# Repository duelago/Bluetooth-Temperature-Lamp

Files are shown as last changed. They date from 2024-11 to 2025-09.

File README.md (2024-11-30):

# <h1>Blåtandstermometerlampan</h1>

En bordslampa som byter färg beroende på yttertemperaturen och som även visar tempen på en liten OLED-skärm.
Lampan kommunicerar med en billig blåtandstermometer som vi installerar alternativ firmware på och placerar utomhus (i närheten).
Kodat i Arduino IDE. Termometern vi ansluter till måste flashas en gång med hjälp av ett pythonscript och lödkolven måste fram. 

Jag printar lådan och locket i PLA med 0.6 nozzle på min Prusa.<br>
Själva toppen av lampan till höger i bild är printad med 0.4 nozzle. Två perimetrar, ingen infill i själva lampan men fästet längst ner har infill. (Prusa slicer har stöd för olika infill på olika lager) Pinnen är ett metallsugrör från ICA

Screenshot 2024-11-10 at 17 25 36 copy

bluetoothesp32

<h2>Själva hjärnan i operationen är en ESP32</h2>

Detta behövs:<br>
ESP32 38 pin- Testad med denna modellen från AliExpress (Jag kör med micro usb-anslutning eftersom jag har ett rejält lager med sådana kablar) https://www.aliexpress.com/item/1005006900641832.html 
Blåtandstermometer - https://www.aliexpress.com/item/1005006458594110.html
LED  - https://www.aliexpress.com/item/1005004950092116.html
OLED-skärm https://www.aliexpress.com/item/32804426981.html
USB-to-TTL adapter (Vet inte vilken som är bra, men typ denna) https://www.aliexpress.com/item/1005004742270942.html
Metallsugrör från ICA eller Amazon https://t.ly/_2JY1
1 st motstånd 100 Ohm
2 skruvar M2.5 
1 micro usb-kabel
Krympslang till LEDen https://www.aliexpress.com/item/1005006991396293.html 
Dupontkablar (female-female) 3st 30cm  och ett gäng 10cm https://www.aliexpress.com/item/1005005501503609.html

3D-printade detaljer i PLA











<h2>Steg ett är att flasha firmware på vår termometer</h2>
Plocka isär den och löd fast kablar enligt denna bild. Dessa ska du sedan koppla till din USB-to-TTL adapter
<b>rx-tx<br>
tx-rx<br>
vbat+- 3.3v<br>
vbat- - ground<br>
rest - reset</b>

bth01

Följ instruktionerna här för hur du flashar din BTH01  https://github.com/pvvx/THB2 <br> (Denna modellen har jag, men det finns varianter https://pvvx.github.io/BTH01/ )<br>

Först måste du flasha .hex filen via terminalen med hjälp av python scriptet. (Finns även bland mina filer) <br>
Typ så här görs det på min mac:<p>


Din COM-port heter något annat. Den får du luska reda på.
<h2>Web-interfacet där du uppdaterar din firmware i fortsättningen ser ut så här</h2>



När du flashat klart, klickar du på  READ under config-taben och ta reda på termometerns MAC-adress. Denna adress klistrar du in i .ino filen före du kompilerar lampans firmware

Sen är det bara att kompilera [.ino](https://github.com/duelago/bluetoothlamp/blob/main/bluetooth-esp32.ino) filen i Arduino IDE. Se till att korrekt esp32 är vald som board och att alla bibliotek är installerade.



<h2>nRF Connect</h2>

Tips. Denna appen är utmärkt för att se mer info om din blåtandstermometer samt för felsökning. Klarar av att decoda temperaturen även när vi kör custom firmware
Screenshot_2024-11-11-08-14-45-61_b5a5c5cb02ca09c784c5d88160e2ec24

<h1>Snöflingelampan</h1>

Denna lampa är en vidareutveckling av blåtandslampan. Utöver temperatur har jag placerat en co2-sensor i lådan, samt kör med sex LEDs istället för endast en. Resultatet är att vi kan presentera mer information genom att varje LED teoretiskt går att styra individuellt. I denna versionen har jag delat upp LEDsen tre och tre där ena sidan visar temp och den andra koldioxidhalten i rummet. Flasha snowflake.ino och studera kopplingsschemat nedan. Själva blåtandsdelen är identisk.

Jag har även gjort en lampa med extra allt. Snowflake Web, snowflake-web.ino. Denna är uppkopplad på wifi och har förutom temp och c02, stöd för en extern väderstation från Holfuy, samt upplyser om när en viss låt spelas på Mix Megapol. Kolla min Whamageddonlampa för mer info. I denna lampa har vi ett webinterface och kan även göra firmwareuppdateringar via websidan (OTA).

https://www.youtube.com/watch?v=6aXL863onwM


bluetooth

Denna co2-sensorn, Scd40 använder jag i snöflingan. Dyr men bra.
https://www.aliexpress.com/item/1005006275318058.html
I övrigt är det bara att följa instruktionerna för blåtandslampan. Skillnaden är att vi måste seriekoppla 6 leds. Hur det görs ser du på skissen. Data in till data ut. Co2-sensorn kan köras på både 3.3V och 5V, men 5 volt rekommenderas.



<h3>Snowflake Web</h3>
Jag kunde inte låta bli så i denna versionen kan du varna för Last Christmas på Megapol, aka Whamageddonlampan, samt se data i en lokal webserver. Denna lampa kräver dock lite installation för att funka och är sämre att ge bort i present, men här har du allt lull-lull. 


<h3>Retroversion med HPDL1414 skärm</h3>

retro

HPDL-1414 finns att köpa här https://www.aliexpress.com/item/32604923707.html

-----
<br>
Mer dokumentation om blåtandsgrunkorna<br> 
https://github.com/pvvx/ATC_MiThermometer#readme

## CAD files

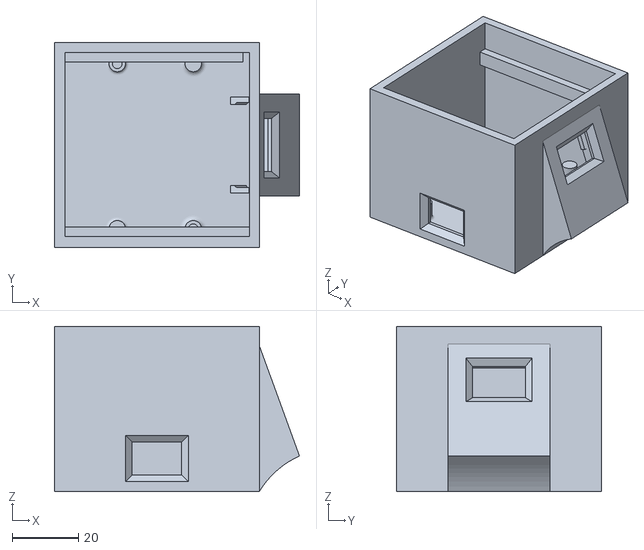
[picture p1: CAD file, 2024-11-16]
bluetooth-lamp-esp32-box.stl
74.1 x 62.0 x 50.0

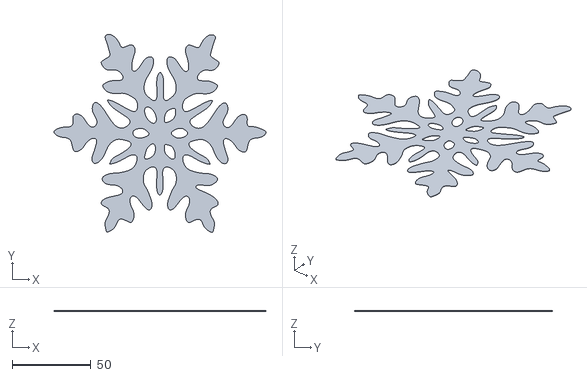
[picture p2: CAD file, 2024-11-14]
snowflake_Part2.stl
135.0 x 126.1 x 0.6

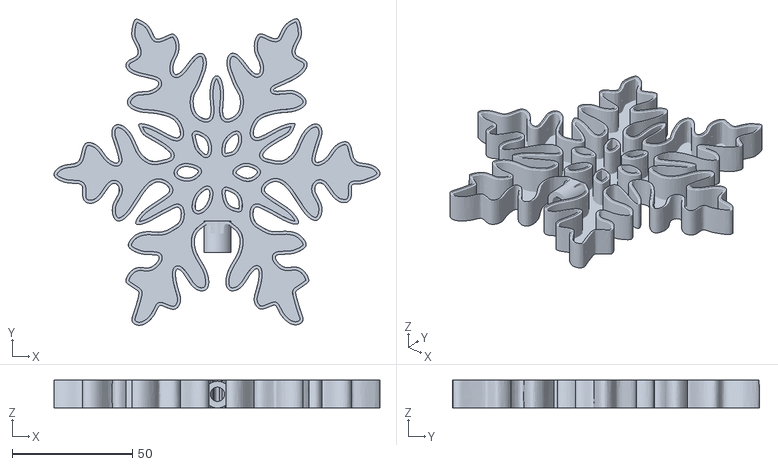
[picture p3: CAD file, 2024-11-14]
snowflake-part1.stl
135.3 x 127.3 x 11.6

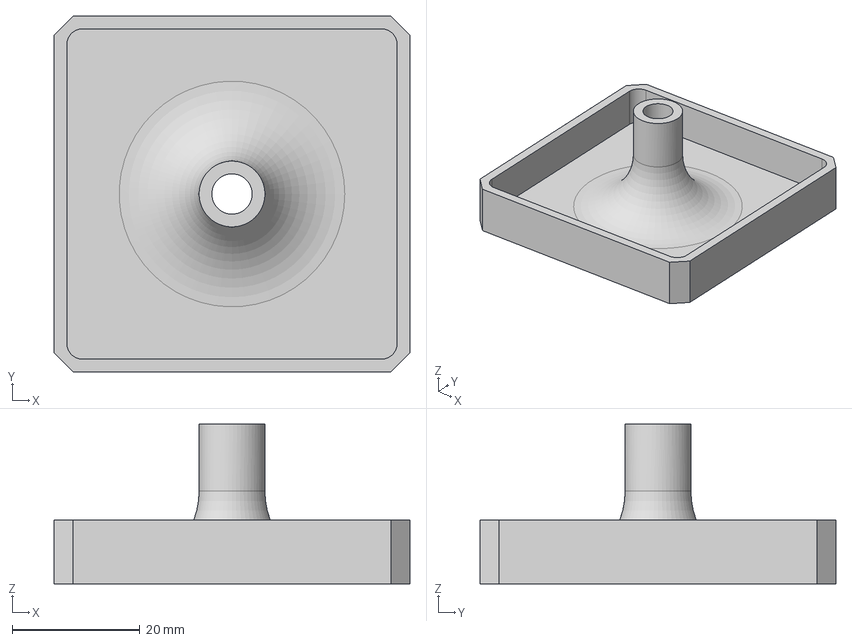
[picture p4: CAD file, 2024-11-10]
bluetooth-box-lid.step
55.7 x 55.7 x 25.0 mm

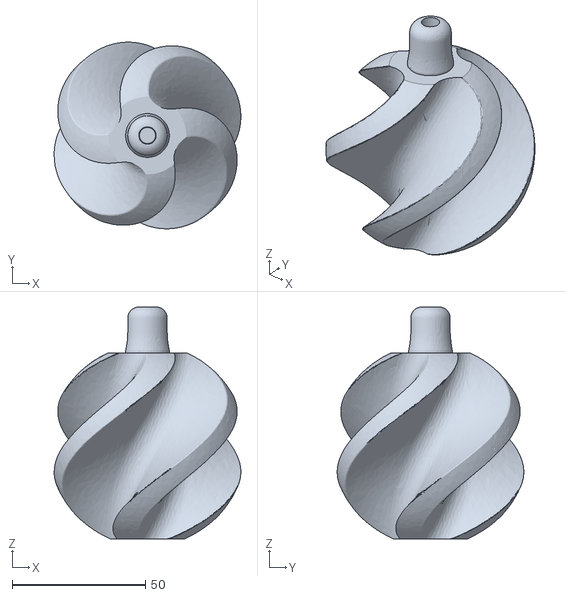
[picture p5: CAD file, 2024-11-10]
bluetooth-lampshade.stl
70.0 x 70.0 x 87.0

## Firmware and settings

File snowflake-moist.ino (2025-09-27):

#include <FastLED.h>
#include <Wire.h>
#include <Adafruit_GFX.h>
#include <Adafruit_SSD1306.h>
#include <NimBLEDevice.h>
#include <WiFiManager.h>
#include <WebServer.h>
#include <ElegantOTA.h>
#include <HTTPClient.h>  
#include <ArduinoJson.h> 
#include <EEPROM.h>  

#define SONG_TITLE_ADDRESS 0
#define DRY_VALUE_ADDRESS 50
#define WET_VALUE_ADDRESS 54

// OLED Display definitions  
#define SCREEN_WIDTH 64
#define SCREEN_HEIGHT 48
#define OLED_RESET -1

#define NUM_LEDS 6
#define DATA_PIN 4

#define OLED_SDA 21
#define OLED_SCL 22

#define MOISTURE_PIN 32

WebServer server(80);

CRGB leds[NUM_LEDS];
// Fixed display declaration for older library
Adafruit_SSD1306 display(OLED_RESET);

// Set the interval for all sensor checks to 45 seconds (45,000 milliseconds)
unsigned long previousMoistureCheckMillis = 0;
unsigned long previousTitleCheckMillis = 0;
unsigned long previousWindUpdateMillis = 0; // Add a variable to track wind update time
const unsigned long sensorCheckInterval = 45000; // 45 seconds (45,000 milliseconds)

const char* apiUrl = "https://listenapi.planetradio.co.uk/api9.2/nowplaying/mme";

unsigned long previousBLEMillis = 0; // Stores the last time BLE scan was triggered
const unsigned long scanInterval = 10000; // Time between BLE scans (e.g., 10 seconds)

const char* apiHost = "api.holfuy.com";

// The updated interval for all checks
const unsigned long updateInterval = 45000;  // 45 seconds in milliseconds

float temperature = 0.0;
float windSpeed = 0.0;
bool hasReceivedReading = false;
const std::string targetMacAddress = "38:1f:8d:97:bd:5d";

//bool blockLEDUpdates = false; // Flag to block other LED updates
// Global flag to control LED behavior
bool isBlinking = false;

// Moisture sensor variables
int moistureValue = 0;
int dryValue = 3000;  // Default dry calibration value
int wetValue = 1000;  // Default wet calibration value

NimBLEScan* pBLEScan;
const int scanTime = 5;

// Function prototypes
void displayCenteredText(String text, int textSize, int yPosition);
void setTemperatureLEDColor(float roundedTemperature);
void setWindSpeedLEDColor(float windSpeed);
void handleMoistureLEDs();
void blinkRedGreen(int duration);
void blinkRedLEDs();
void decodeServiceData(const std::string& payload);
void checkWiFiConnection();
uint16_t decodeLittleEndianU16(uint8_t lowByte, uint8_t highByte);
void testDisplay();
void testLEDs();

// WiFi reconnection function
void checkWiFiConnection() {
    if (WiFi.status() != WL_CONNECTED) {
        Serial.println("WiFi disconnected. Attempting to reconnect...");
        WiFi.disconnect();
        delay(1000);
        
        // Try to reconnect
        WiFi.begin();
        
        int attempts = 0;
        while (WiFi.status() != WL_CONNECTED && attempts < 20) {
            delay(500);
            Serial.print(".");
            attempts++;
        }
        
        if (WiFi.status() == WL_CONNECTED) {
            Serial.println();
            Serial.print("WiFi reconnected! IP: ");
            Serial.println(WiFi.localIP());
            Serial.print("Signal strength (RSSI): ");
            Serial.println(WiFi.RSSI());
        } else {
            Serial.println();
            Serial.println("Failed to reconnect to WiFi");
        }
    }
}

void blinkRedGreen(int duration) {
    unsigned long start = millis();
    unsigned long prevBlinkMillis = 0;
    int interval = 999; // Blink interval in milliseconds
    bool isRedOnLed4 = true; // Start with LED 4 as red

    while (millis() - start < duration) {
        unsigned long currentMillis = millis();

        // Check if it's time to toggle the color
        if (currentMillis - prevBlinkMillis >= interval) {
            prevBlinkMillis = currentMillis; // Save the current time

            if (isRedOnLed4) {
                leds[4] = CRGB::Cyan;   // Set LED at index 4 to red
                leds[5] = CRGB::Magenta; // Set LED at index 5 to green
            } else {
                leds[4] = CRGB::Magenta; // Set LED at index 4 to green
                leds[5] = CRGB::Cyan;   // Set LED at index 5 to red
            }

            FastLED.show();
            isRedOnLed4 = !isRedOnLed4; // Toggle the LED colors
        }

        // Do other non-blocking tasks here if needed
    }
}

// Function to write values to EEPROM
void writeDryValueToEEPROM(int value) {
    EEPROM.writeInt(DRY_VALUE_ADDRESS, value);
    EEPROM.commit();
}

void writeWetValueToEEPROM(int value) {
    EEPROM.writeInt(WET_VALUE_ADDRESS, value);
    EEPROM.commit();
}

// Function to read values from EEPROM
int readDryValueFromEEPROM() {
    int value = EEPROM.readInt(DRY_VALUE_ADDRESS);
    return (value == 0 || value == -1) ? 3000 : value; // Default if not set
}

int readWetValueFromEEPROM() {
    int value = EEPROM.readInt(WET_VALUE_ADDRESS);
    return (value == 0 || value == -1) ? 1000 : value; // Default if not set
}

// Function to write the song title to EEPROM
void writeSongTitleToEEPROM(const String& songTitle) {
    int len = songTitle.length();
    for (int i = 0; i < len; i++) {
        EEPROM.write(SONG_TITLE_ADDRESS + i, songTitle[i]);
    }
    EEPROM.write(SONG_TITLE_ADDRESS + len, '\0');  // Null-terminate the string
    EEPROM.commit();  // Save changes to EEPROM
}

// Function to read the song title from EEPROM
String readSongTitleFromEEPROM() {
    String songTitle = "";
    for (int i = SONG_TITLE_ADDRESS; i < SONG_TITLE_ADDRESS + 32; i++) {
        char c = EEPROM.read(i);
        if (c == '\0') break;
        songTitle += c;
    }
    return songTitle;
}

// Function to handle the form for setting the song title
void handleSetSongTitle() {
    String songTitle = server.arg("songTitle");  // Get the song title from the form
    if (songTitle.length() > 0) {
        writeSongTitleToEEPROM(songTitle);  // Store it in EEPROM
    }
    server.send(200, "text/html", "<html><body><h1>Song Title Saved!</h1><a href='/'>Back</a></body></html>");
}

// Function to handle calibration form
void handleCalibration() {
    String dryVal = server.arg("dryValue");
    String wetVal = server.arg("wetValue");
    
    if (dryVal.length() > 0) {
        dryValue = dryVal.toInt();
        writeDryValueToEEPROM(dryValue);
    }
    
    if (wetVal.length() > 0) {
        wetValue = wetVal.toInt();
        writeWetValueToEEPROM(wetValue);
    }
    
    server.send(200, "text/html", "<html><body><h1>Calibration Values Saved!</h1><a href='/'>Back</a></body></html>");
}

// Function to make an HTTP request and parse JSON with retry and timeout settings
String getSongTitle() {
    // Check and reconnect WiFi if needed
    checkWiFiConnection();
    
    if (WiFi.status() != WL_CONNECTED) {
        Serial.println("WiFi still not connected, cannot fetch song title");
        return "WiFi disconnected";
    }
    
    Serial.println("Attempting to connect to: " + String(apiUrl));
    
    HTTPClient http;
    
    // Configure HTTP client with timeouts
    http.setTimeout(10000); // 10 second timeout
    http.setConnectTimeout(5000); // 5 second connection timeout
    http.setReuse(false); // Don't reuse connections
    
    // Add headers
    http.addHeader("User-Agent", "ESP32-Snowflake/1.0");
    http.addHeader("Accept", "application/json");
    
    if (!http.begin(apiUrl)) {
        Serial.println("HTTP begin failed");
        return "HTTP begin error";
    }
    
    int httpResponseCode = http.GET();
    Serial.print("HTTP Response Code: ");
    Serial.println(httpResponseCode);

    if (httpResponseCode > 0) {
        String payload = http.getString();
        Serial.println("HTTP Response received, length: " + String(payload.length()));
        
        if (payload.length() > 0) {
            Serial.println("HTTP Response: " + payload.substring(0, min(200, (int)payload.length()))); // Show first 200 chars

            // Parse JSON
            StaticJsonDocument<1024> doc;
            DeserializationError error = deserializeJson(doc, payload);

            if (error) {
                Serial.print("JSON Deserialization failed: ");
                Serial.println(error.f_str());
                http.end();
                return "Error parsing JSON";
            }

            // Extract the song title from the JSON response
            const char* songTitle = doc["TrackTitle"];
            http.end();
            return songTitle ? String(songTitle) : "No song data";
        } else {
            Serial.println("Empty response received");
            http.end();
            return "Empty response";
        }
    } else {
        Serial.print("HTTP GET request failed, error: ");
        Serial.println(http.errorToString(httpResponseCode).c_str());
        Serial.print("WiFi status: ");
        Serial.println(WiFi.status());
        http.end();
        return "HTTP error";
    }
}

// Function to compare two strings case-insensitively
bool caseInsensitiveCompare(const char* str1, const char* str2) {
    while (*str1 && *str2) {
        if (tolower(*str1) != tolower(*str2)) {
            return false;
        }
        str1++;
        str2++;
    }
    return *str1 == *str2;
}

// Helper function to decode a little-endian 16-bit unsigned integer
uint16_t decodeLittleEndianU16(uint8_t lowByte, uint8_t highByte) {
    return (uint16_t)((highByte << 8) | lowByte);
}

// Function to decode the raw service data and update the temperature
void decodeServiceData(const std::string& payload) {
    if (payload.length() >= 14 && payload[0] == 0x40) {
        int16_t temp_int = (payload[6] & 0xff) | ((payload[7] & 0xff) << 8);
        temperature = temp_int / 100.0;
        Serial.print("Temperature: ");
        Serial.print(temperature);
        Serial.println(" °C");

        hasReceivedReading = true;  // Set flag to true once we receive a valid reading

        // Update display and LED color
        setTemperatureLEDColor(round(temperature));
        displayCenteredText(String((int)round(temperature)), 2, 32);
    }
}

// Callback class to handle BLE advertisements
class MyAdvertisedDeviceCallbacks : public NimBLEAdvertisedDeviceCallbacks {
    void onResult(NimBLEAdvertisedDevice* advertisedDevice) {
        if (caseInsensitiveCompare(advertisedDevice->getAddress().toString().c_str(), targetMacAddress.c_str())) {
            if (advertisedDevice->haveServiceData()) {
                decodeServiceData(advertisedDevice->getServiceData());
            } else {
                Serial.println("No service data available.");
            }
        }
    }
};

// FIXED: Function to display centered text on the OLED screen
void displayCenteredText(String text, int textSize, int yPosition) {
    display.clearDisplay();
    display.setTextSize(textSize);
    display.setTextColor(WHITE, BLACK);
    display.setTextWrap(false);
    
    // For 64x48 display - much smaller calculations needed
    int charWidth = 6 * textSize;  // Each character width including spacing
    int charHeight = 8 * textSize; // Each character height
    
    int textWidth = text.length() * charWidth;
    
    // Center horizontally on 64-pixel wide screen
    int xPosition = (SCREEN_WIDTH - textWidth) / 2;
    
    // For 48-pixel tall screen, adjust Y positioning
    int finalYPosition = yPosition;
    if (yPosition == -1) {
        // Center vertically
        finalYPosition = (SCREEN_HEIGHT - charHeight) / 2;
    }
    
    // Bounds checking for small screen
    if (xPosition < 0) xPosition = 0;
    if (xPosition + textWidth > SCREEN_WIDTH) xPosition = SCREEN_WIDTH - textWidth;
    if (xPosition < 0) xPosition = 0; // If text is too wide, align left
    
    if (finalYPosition < 0) finalYPosition = 0;
    if (finalYPosition + charHeight > SCREEN_HEIGHT) finalYPosition = SCREEN_HEIGHT - charHeight;
    
    display.setCursor(xPosition, finalYPosition);
    display.print(text);
    display.display();
    
    Serial.print("64x48 Display - Text: '");
    Serial.print(text);
    Serial.print("' Size: ");
    Serial.print(textSize);
    Serial.print(" Pos: (");
    Serial.print(xPosition);
    Serial.print(",");
    Serial.print(finalYPosition);
    Serial.print(") TextWidth: ");
    Serial.print(textWidth);
    Serial.print(" Screen: ");
    Serial.print(SCREEN_WIDTH);
    Serial.print("x");
    Serial.println(SCREEN_HEIGHT);
}

void updateWindSpeed() {
    // Check and reconnect WiFi if needed
    checkWiFiConnection();
    
    if (WiFi.status() != WL_CONNECTED) {
        Serial.println("WiFi still not connected, cannot fetch wind speed");
        return;
    }
    
    HTTPClient client;
    String url = "https://api.holfuy.com/live/?s=214&pw=correcthorsebatterystaple&m=JSON&tu=C&su=m/s";
    
    Serial.println("Attempting to connect to Holfuy API for wind data: " + url);
    
    // Configure HTTP client with timeouts
    client.setTimeout(10000); // 10 second timeout
    client.setConnectTimeout(5000); // 5 second connection timeout
    client.setReuse(false); // Don't reuse connections
    
    // Add headers
    client.addHeader("User-Agent", "ESP32-Snowflake/1.0");
    client.addHeader("Accept", "application/json");

    // Begin the HTTP request to the API
    if (!client.begin(url)) {
        Serial.println(F("Holfuy API connection failed"));
        return;
    }

    // Send the HTTP GET request
    int httpCode = client.GET();
    Serial.print("Holfuy HTTP Response Code: ");
    Serial.println(httpCode);

    // Check if the GET request was successful
    if (httpCode > 0) {
        String payload = client.getString();  // Get the response payload
        
        // Print the response to the Serial monitor
        Serial.println("Holfuy Response length: " + String(payload.length()));
        if (payload.length() > 0) {
            Serial.println("Holfuy Response: " + payload.substring(0, min(200, (int)payload.length())));

            // Parse the JSON response
            StaticJsonDocument<512> doc;
            DeserializationError error = deserializeJson(doc, payload);

            if (!error) {
                // Successfully parsed the JSON, get the wind speed
                float speed = doc["wind"]["speed"];
                Serial.print("Wind Speed Holfuy: ");
                Serial.print(speed);
                Serial.println(" m/s");

                // Set the LED color based on the wind speed
                setWindSpeedLEDColor(speed);
                windSpeed = speed;  // Store the wind speed
            } else {
                // Handle JSON parsing error
                Serial.print(F("JSON deserialization failed: "));
                Serial.println(error.f_str());
            }
        } else {
            Serial.println("Empty response from Holfuy API");
        }
    } else {
        // If the GET request failed
        Serial.println("Holfuy HTTP request failed, error code: " + String(httpCode));
        Serial.print("WiFi status: ");
        Serial.println(WiFi.status());
    }

    // Close the connection
    client.end();
}

void setWindSpeedLEDColor(float windSpeed) {
    // LEDs at index 2 and 3 for wind speed (0-25+ m/s scale)
    if (windSpeed >= 0 && windSpeed < 3) {
        fill_solid(leds + 2, 2, 0xFF44DD);  // Pink (0-3 m/s)
    } else if (windSpeed >= 3 && windSpeed < 6) {
        fill_solid(leds + 2, 2, 0x0006FF);  // Blue (3-6 m/s)
    } else if (windSpeed >= 6 && windSpeed <= 9) {
        fill_solid(leds + 2, 2, 0x00FF06);  // Green (6-9 m/s)
    } else if (windSpeed > 9 && windSpeed <= 12) {
        fill_solid(leds + 2, 2, 0xFFF600);  // Yellow (9-12 m/s)
    } else if (windSpeed > 12 && windSpeed <= 18) {
        fill_solid(leds + 2, 2, 0xFFA500);  // Orange (12-18 m/s)
    } else if (windSpeed > 18 && windSpeed <= 22) {
        fill_solid(leds + 2, 2, 0xFF0000);  // Red (18-22 m/s)
    } else if (windSpeed > 22) {
        fill_solid(leds + 2, 2, 0x800080);  // Purple (22+ m/s)
    }

    FastLED.show();
}

void setTemperatureLEDColor(float roundedTemperature) {
    // First two LEDs for temperature
    if (roundedTemperature >= -50 && roundedTemperature < -5) {
        fill_solid(leds, 2, 0xFF44DD);  // Pink
    } else if (roundedTemperature >= -5 && roundedTemperature < 0) {
        fill_solid(leds, 2, 0x0006FF);  // Blue
    } else if (roundedTemperature >= 0 && roundedTemperature <= 5) {
        fill_solid(leds, 2, 0x00FF06);  // Green
    } else if (roundedTemperature > 5 && roundedTemperature <= 10) {
        fill_solid(leds, 2, 0xFFF600);  // Yellow
    } else if (roundedTemperature > 10 && roundedTemperature <= 15) {
        fill_solid(leds, 2, 0xFFA500);  // Orange
    } else if (roundedTemperature > 15 && roundedTemperature <= 20) {
        fill_solid(leds, 2, 0xFF0000);  // Red
    } else if (roundedTemperature > 20 && roundedTemperature <= 45) {
        fill_solid(leds, 2, 0x800080);  // Purple
    } else {
        fill_solid(leds, 2, 0x000000);  // Off
    }

    FastLED.show();
}
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
void loop() {
    unsigned long currentMillis = millis();

    // Check WiFi connection periodically
    static unsigned long lastWiFiCheck = 0;
    if (currentMillis - lastWiFiCheck >= 30000) { // Check every 30 seconds
        lastWiFiCheck = currentMillis;
        if (WiFi.status() != WL_CONNECTED) {
            Serial.println("WiFi disconnected in main loop");
            checkWiFiConnection();
        }
    }

    // Set unified sensor check interval to 45 seconds (45,000 milliseconds)
    if (currentMillis - previousTitleCheckMillis >= sensorCheckInterval) {
        previousTitleCheckMillis = currentMillis;

        // Check for the current song title
        String storedSongTitle = readSongTitleFromEEPROM();  // Get the stored song title
        String currentSongTitle = getSongTitle();  // Get the current track title from API

        // If the stored song title matches the current track title, start blinking red LEDs
        if (caseInsensitiveCompare(storedSongTitle.c_str(), currentSongTitle.c_str())) {
            isBlinking = true; // Set flag to indicate LED control for blinking
        } else {
            isBlinking = false; // Clear flag to return to normal LED behavior
        }
    }

    // Handle LED behavior based on the flag
    if (isBlinking) {
        // Blink the LEDs red continuously if the flag is set
        blinkRedLEDs();
    } else {
        // Normal LED handling and temperature display when not blinking
        if (!hasReceivedReading) {
            fill_solid(leds, NUM_LEDS, CRGB::White);
            FastLED.show();
            displayCenteredText("OFF", 2, 32);
        } else {
            handleMoistureLEDs();
        }
    }

    // Existing BLE scan logic
    if (currentMillis - previousBLEMillis >= scanInterval) {
        previousBLEMillis = currentMillis;
        pBLEScan->start(scanTime, false);
        Serial.println("Scanning...");
    }

    // Update wind speed every 45 seconds
    if (currentMillis - previousWindUpdateMillis >= sensorCheckInterval) {
        previousWindUpdateMillis = currentMillis;
        updateWindSpeed(); // Update wind speed every 45 seconds
    }

    // Handle OTA updates and web server requests
    ElegantOTA.loop();
    server.handleClient();
}

// Non-blocking blinkRedLEDs function
void blinkRedLEDs() {
    static unsigned long previousBlinkMillis = 0;
    static bool isRed = false;
    unsigned long currentMillis = millis();

    if (currentMillis - previousBlinkMillis >= 500) { // 500ms interval
        previousBlinkMillis = currentMillis;
        isRed = !isRed; // Toggle between red and off

        if (isRed) {
            fill_solid(leds, NUM_LEDS, CRGB::Red); // Turn all LEDs red
        } else {
            fill_solid(leds, NUM_LEDS, CRGB::Black); // Turn off LEDs
        }
        FastLED.show();
    }
}

// Debug function to test display functionality
void testDisplay() {
    Serial.println("Running display test sequence...");
    
    // Test 1: Clear display
    display.clearDisplay();
    display.display();
    delay(500);
    
    // Test 2: Single pixel
    display.clearDisplay();
    display.drawPixel(64, 32, WHITE);
    display.display();
    delay(1000);
    
    // Test 3: Simple text
    display.clearDisplay();
    display.setTextSize(1);
    display.setTextColor(WHITE);
    display.setCursor(0, 0);
    display.print(" Kasewood");
    display.display();
    delay(2000);
    
    // Test 4: Centered large text
    displayCenteredText("OK", 3, 20);
    delay(2000);
    
    Serial.println("Display test sequence completed");
}

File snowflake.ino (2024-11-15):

#include <FastLED.h>
#include <Wire.h>
#include <Adafruit_GFX.h>
#include <Adafruit_SSD1306.h>
#include <SparkFun_SCD4x_Arduino_Library.h>
#include <NimBLEDevice.h>

#define OLED_RESET -1
#define NUM_LEDS 6
#define DATA_PIN 4

#define OLED_SDA 21
#define OLED_SCL 22

#define CO2_SDA 17
#define CO2_SCL 16

CRGB leds[NUM_LEDS];
Adafruit_SSD1306 display(128, 64, &Wire, OLED_RESET);
SCD4x scd4x(SCD4x_SENSOR_SCD40);

float temperature = 0.0;
bool hasReceivedReading = false;
const std::string targetMacAddress = "38:1f:8d:97:bd:5d";

NimBLEScan* pBLEScan;
const int scanTime = 5;

void showRainbowEffect(int duration) {
    unsigned long start = millis();
    while (millis() - start < duration) {
        for (int j = 0; j < 256; j++) {  // Cycle through the rainbow colors
            
      //    for (int i = 0; i < NUM_LEDS; i++) {   //Kör regnbåge på alla sex LEDS
            for (int i = 3; i < NUM_LEDS; i++) {  // Kör regnbåge på tre 
                
                leds[i] = CHSV((i * 256 / NUM_LEDS + j) % 256, 255, 255);
            }
            FastLED.show();
            delay(20);  // Delay for smooth transition
        }
    }
}



// Function to compare two strings case-insensitively
bool caseInsensitiveCompare(const char* str1, const char* str2) {
    while (*str1 && *str2) {
        if (tolower(*str1) != tolower(*str2)) {
            return false;
        }
        str1++;
        str2++;
    }
    return *str1 == *str2;
}

// Callback class to handle BLE advertisements
class MyAdvertisedDeviceCallbacks : public NimBLEAdvertisedDeviceCallbacks {
    void onResult(NimBLEAdvertisedDevice* advertisedDevice) {
        if (caseInsensitiveCompare(advertisedDevice->getAddress().toString().c_str(), targetMacAddress.c_str())) {
            if (advertisedDevice->haveServiceData()) {
                decodeServiceData(advertisedDevice->getServiceData());
            } else {
                Serial.println("No service data available.");
            }
        }
    }
};

// CO2 sensor thresholds and variables
int co2High = 1300;
int co2Low = 1200;
uint16_t currentCO2 = 0;
bool isCO2High = false;

// Function prototypes
void displayCenteredText(String text, int textSize, int yPosition);
void setTemperatureLEDColor(float roundedTemperature);
void handleCO2LEDs();
void showRainbowEffect(int duration);
uint16_t decodeLittleEndianU16(uint8_t lowByte, uint8_t highByte);  // Function prototype

// Helper function to decode a little-endian 16-bit unsigned integer
uint16_t decodeLittleEndianU16(uint8_t lowByte, uint8_t highByte) {
    return (uint16_t)((highByte << 8) | lowByte);
}

// Function to decode the raw service data and update the temperature
void decodeServiceData(const std::string& payload) {
    if (payload.length() >= 14 && payload[0] == 0x40) {
        int16_t temp_int = (payload[6] & 0xff) | ((payload[7] & 0xff) << 8);
        temperature = temp_int / 100.0;
        Serial.print("Temperature: ");
        Serial.print(temperature);
        Serial.println(" °C");

        hasReceivedReading = true;  // Set flag to true once we receive a valid reading

        // Update display and LED color
        setTemperatureLEDColor(round(temperature));
        displayCenteredText(String((int)round(temperature)), 2, 15);
    }
}

// Function to display centered text on the OLED screen
void displayCenteredText(String text, int textSize, int yPosition) {
    display.clearDisplay();
    display.setTextSize(textSize);
    display.setTextColor(WHITE);

    int16_t x1, y1;
    uint16_t width, height;
    display.getTextBounds(text, 0, 0, &x1, &y1, &width, &height);

    int xPosition = (display.width() - width) / 2;
    int adjustedYPosition = 32;  // Adjusted Y position to start on the third row

    display.setCursor(xPosition, adjustedYPosition);
    display.print(text);
    display.display();
}

// Set LED color based on temperature
void setTemperatureLEDColor(float roundedTemperature) {
    Serial.print("Setting LED color based on temperature: ");
    Serial.println(roundedTemperature);

    if (roundedTemperature >= -50 && roundedTemperature < -5) {
        fill_solid(leds, 3, 0xFF44DD);  // Pink
    } else if (roundedTemperature >= -5 && roundedTemperature < 0) {
        fill_solid(leds, 3, 0x0006FF);  // Blue
    } else if (roundedTemperature >= 0 && roundedTemperature <= 5) {
        fill_solid(leds, 3, 0x00FF06);  // Green
    } else if (roundedTemperature > 5 && roundedTemperature <= 10) {
        fill_solid(leds, 3, 0xFFF600);  // Yellow
    } else if (roundedTemperature > 10 && roundedTemperature <= 15) {
        fill_solid(leds, 3, 0xFFA500);  // Orange
    } else if (roundedTemperature > 15 && roundedTemperature <= 20) {
        fill_solid(leds, 3, 0xFF0000);  // Red
    } else if (roundedTemperature > 20 && roundedTemperature <= 45) {
        fill_solid(leds, 3, 0x800080);  // Purple
    } else {
        fill_solid(leds, 3, 0x000000);  // Off
    }

    FastLED.show();
}

void handleCO2LEDs() {
    if (scd4x.readMeasurement()) {
        uint16_t currentCO2 = scd4x.getCO2();
        Serial.print("CO2 Level: ");
        Serial.println(currentCO2);

        // Show rainbow effect when CO2 > 1300 ppm
        if (currentCO2 >= 1300) {
            showRainbowEffect(5000);
        } 
        // Set LED color based on CO2 level if it's below 1300 ppm
        else if (currentCO2 <= 650) {
            fill_solid(leds + 3, 3, CRGB::Green);  // CO2: <= 650 ppm, Green
        } else if (currentCO2 > 650 && currentCO2 <= 800) {
            fill_solid(leds + 3, 3, CRGB::Yellow); // CO2: 651 - 800 ppm, Yellow
        } else if (currentCO2 > 800 && currentCO2 <= 1000) {
            fill_solid(leds + 3, 3, CRGB::Orange); // CO2: 801 - 1000 ppm, Orange
        } else if (currentCO2 > 1000 && currentCO2 <= 1200) {
            fill_solid(leds + 3, 3, CRGB::Red);    // CO2: 1001 - 1200 ppm, Red
        } else if (currentCO2 > 1200 && currentCO2 <= 1299) {
            fill_solid(leds + 3, 3, CRGB::Purple); // CO2: 1201 - 1299 ppm, Purple
        } else {
            fill_solid(leds + 3, 3, CRGB::White);  // CO2: > 1299 ppm, White (or another default color)
        }

        FastLED.show();
    }
}
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

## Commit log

2024-11-10 Update and rename holfuy32.ino to bluetooth-esp32.ino
2024-11-16 Add files via upload
    Lite större fötter som esp32an vilar på i lådan
    [bluetooth-lamp-esp32-box.stl]
2024-11-27 Update hpdl1414-esp32.ino
    Funkar
2025-04-05 Update hpdl1414-esp32.ino
    Sommartid
2025-09-20 Update snowflake-moist.ino
    moist funkar. vind inte fixad
    [snowflake-moist.ino]
